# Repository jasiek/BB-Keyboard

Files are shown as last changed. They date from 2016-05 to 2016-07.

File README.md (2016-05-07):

BB-Keyboard
=================

> A complete module that acts as a SPI/I2C keyboard, which uses OEM surplus Blackberry keyboards and micro switches.

### Bill of materials

#### [Blackberry Q5 Keyboard](http://www.aliexpress.com/item/New-Original-For-Blackberry-Q5-Housing-Keypad-Keyboard-Qwerty-Black-Or-White-Free-Shipping/32337504795.html) ($3)
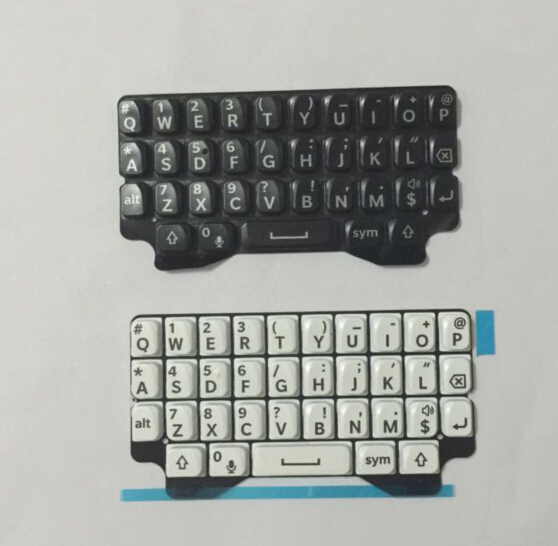
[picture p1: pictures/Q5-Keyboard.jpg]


#### [3x4x2mm SMD Tactile Switches](http://www.aliexpress.com/item/200PCS-3-4-2MM-3X4X2mm-SMD-Tact-2P-miniature-micro-switch-button-switch-new-Original-Push/32595638808.html) ($4)
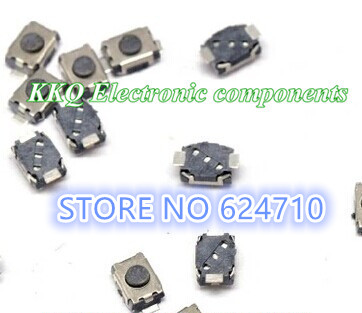
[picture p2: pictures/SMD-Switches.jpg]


#### TBD... looking for a keboard/matrix scanner.

|Chip|Description|Package|Price ($)|OK?|
|---|---|---|---|---|
|LM8330|I2C Keypad Controller|DSBGA|1.70|:x: (2x2mm BGA)|
|MAX7360|I²C-Interfaced Key-Switch Controller|QFN|4.65|:ok:, expensive|
|ADP5586|Keypad Decoder and I/O Exp|BGA|2.08|:x: (1.6x1.6 BGA)|
|BU1852GUW|Key encoder|BGA|2.07|:x: (4mm BGA)|
|TCA8418|I2C Controlled Keypad Scan IC|QFN|3.15|:ok:|

This is a work-in-progress.

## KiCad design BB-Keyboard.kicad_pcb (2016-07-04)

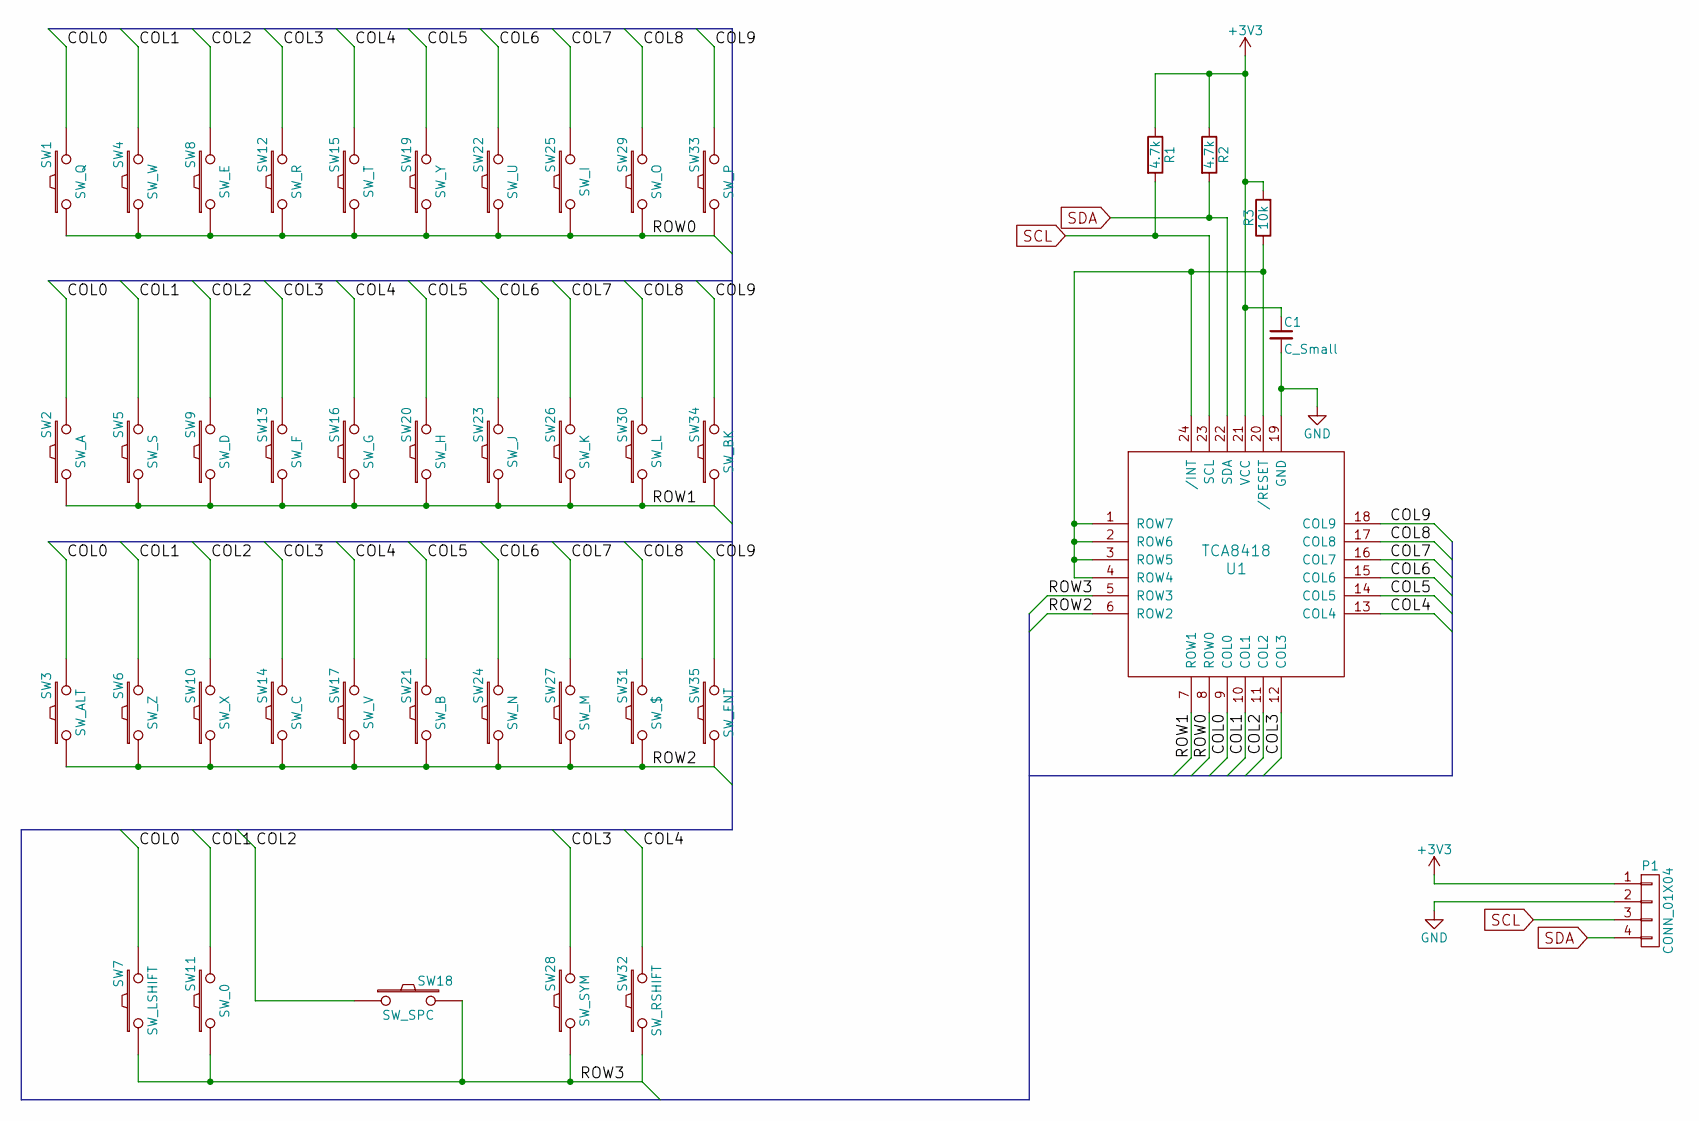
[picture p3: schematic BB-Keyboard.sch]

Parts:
C1: C_Small; C_1206_HandSoldering
P1: CONN_01X04; Socket_Strip_Straight_1x04
R1, R2: 4.7k; R_1206_HandSoldering
R3: 10k; R_1206_HandSoldering
SW1: SW_Q; SMD_Switch_4x3mm
SW2: SW_A; SMD_Switch_4x3mm
SW3: SW_ALT; SMD_Switch_4x3mm
SW4: SW_W; SMD_Switch_4x3mm
SW5: SW_S; SMD_Switch_4x3mm
SW6: SW_Z; SMD_Switch_4x3mm
SW7: SW_LSHIFT; SMD_Switch_4x3mm
SW8: SW_E; SMD_Switch_4x3mm
SW9: SW_D; SMD_Switch_4x3mm
SW10: SW_X; SMD_Switch_4x3mm
SW11: SW_0; SMD_Switch_4x3mm
SW12: SW_R; SMD_Switch_4x3mm
SW13: SW_F; SMD_Switch_4x3mm
SW14: SW_C; SMD_Switch_4x3mm
SW15: SW_T; SMD_Switch_4x3mm
SW16: SW_G; SMD_Switch_4x3mm
SW17: SW_V; SMD_Switch_4x3mm
SW18: SW_SPC; SMD_Switch_4x3mm
SW19: SW_Y; SMD_Switch_4x3mm
SW20: SW_H; SMD_Switch_4x3mm
SW21: SW_B; SMD_Switch_4x3mm
SW22: SW_U; SMD_Switch_4x3mm
SW23: SW_J; SMD_Switch_4x3mm
SW24: SW_N; SMD_Switch_4x3mm
SW25: SW_I; SMD_Switch_4x3mm
SW26: SW_K; SMD_Switch_4x3mm
SW27: SW_M; SMD_Switch_4x3mm
SW28: SW_SYM; SMD_Switch_4x3mm
SW29: SW_O; SMD_Switch_4x3mm
SW30: SW_L; SMD_Switch_4x3mm
SW31: SW_$; SMD_Switch_4x3mm
SW32: SW_RSHIFT; SMD_Switch_4x3mm
SW33: SW_P; SMD_Switch_4x3mm
SW34: SW_BK; SMD_Switch_4x3mm
SW35: SW_ENT; SMD_Switch_4x3mm
U1: TCA8418; TCA8418RTWR

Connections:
+3V3: C1.1, P1.1, R1.1, R2.1, R3.2, U1.21 (VCC)
/COL0: SW1.2, SW2.2, SW3.2, SW7.2, U1.9 (COL0)
/COL1: SW4.2, SW5.2, SW6.2, SW11.2, U1.10 (COL1)
/COL2: SW8.2, SW9.2, SW10.2, SW18.1, U1.11 (COL2)
/COL3: SW12.2, SW13.2, SW14.2, SW28.2, U1.12 (COL3)
/COL4: SW15.2, SW16.2, SW17.2, SW32.2, U1.13 (COL4)
/COL5: SW19.2, SW20.2, SW21.2, U1.14 (COL5)
/COL6: SW22.2, SW23.2, SW24.2, U1.15 (COL6)
/COL7: SW25.2, SW26.2, SW27.2, U1.16 (COL7)
/COL8: SW29.2, SW30.2, SW31.2, U1.17 (COL8)
/COL9: SW33.2, SW34.2, SW35.2, U1.18 (COL9)
/ROW0: SW1.1, SW4.1, SW8.1, SW12.1, SW15.1, SW19.1, SW22.1, SW25.1, SW29.1, SW33.1, U1.8 (ROW0)
/ROW1: SW2.1, SW5.1, SW9.1, SW13.1, SW16.1, SW20.1, SW23.1, SW26.1, SW30.1, SW34.1, U1.7 (ROW1)
/ROW2: SW3.1, SW6.1, SW10.1, SW14.1, SW17.1, SW21.1, SW24.1, SW27.1, SW31.1, SW35.1, U1.6 (ROW2)
/ROW3: SW7.1, SW11.1, SW18.2, SW28.1, SW32.1, U1.5 (ROW3)
GND: C1.2, P1.2, U1.19 (GND)
unnamed: R3.1, U1.1 (ROW7), U1.2 (ROW6), U1.3 (ROW5), U1.4 (ROW4), U1.20 (/RESET), U1.24 (/INT)
SCL: P1.3, R1.2, U1.23 (SCL)
SDA: P1.4, R2.2, U1.22 (SDA)

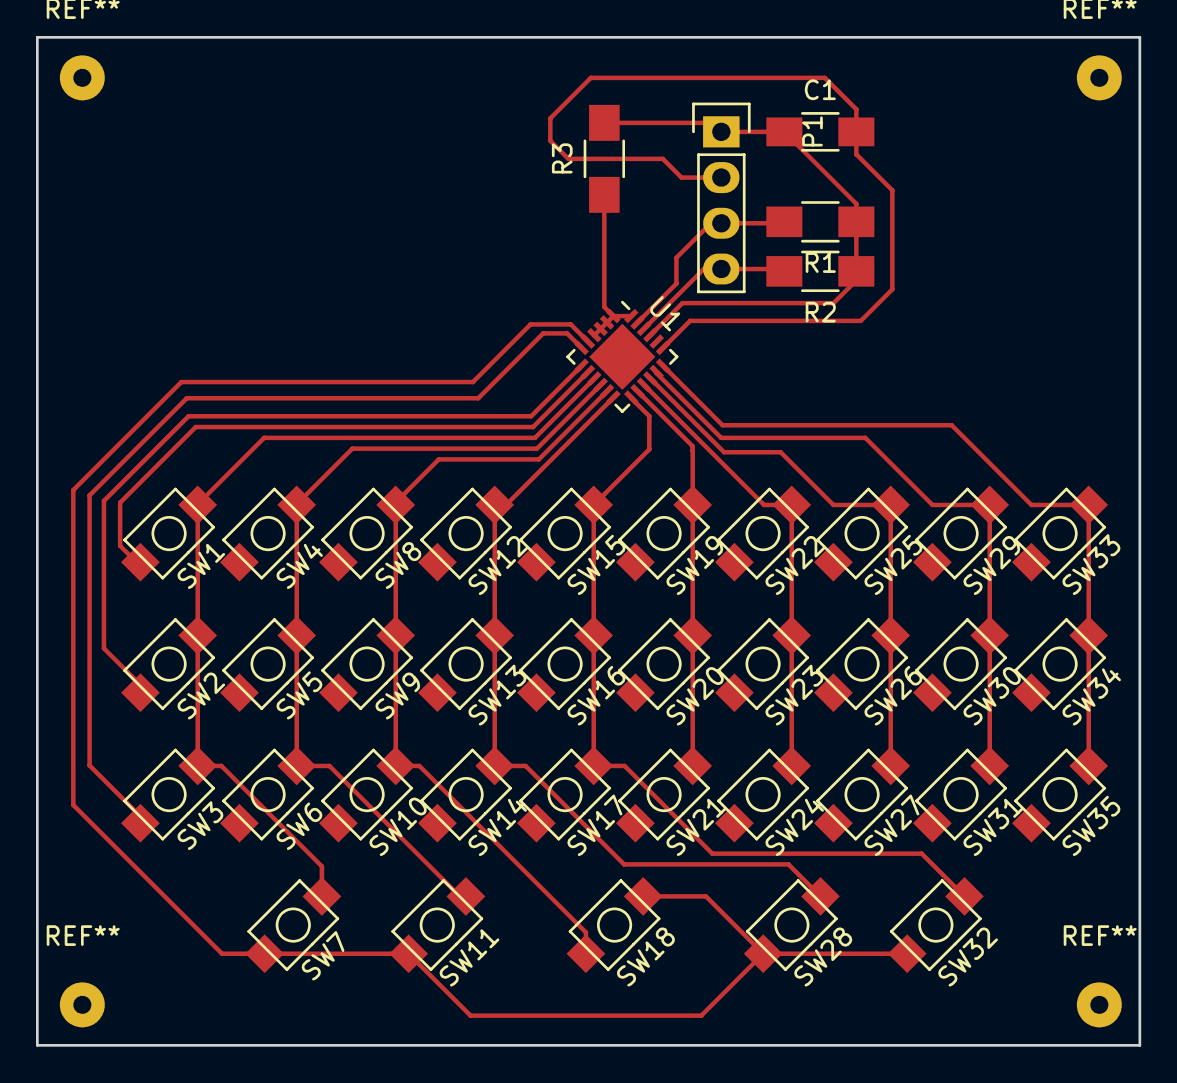
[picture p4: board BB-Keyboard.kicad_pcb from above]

Board: 2 copper layers, 61.2 x 56.0 mm, 41 parts (0 on the bottom side), 19 nets.

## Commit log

2016-05-07 Initial commit.
    [BB-Keyboard.kicad_pcb, BB-Keyboard.sch]
2016-05-08 Buses, labels, et al.
    [BB-Keyboard.sch]
2016-07-02 More labels and buses.
    [BB-Keyboard.sch]
2016-07-02 Created a schematic symbol for TCA8418.
2016-07-02 Finished schematic.
    [BB-Keyboard.sch]
2016-07-02 WIP, component outline changed, but not reflected on PCB.
    [BB-Keyboard.sch]
2016-07-04 Aligned everything, but the alignment isn't right at all. Needs to be wider.
    [BB-Keyboard.kicad_pcb]
